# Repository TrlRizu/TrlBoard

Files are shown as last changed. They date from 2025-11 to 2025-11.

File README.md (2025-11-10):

<h1 align="center">TRL BOARD</h1>
<h3 align="center">ESP32-S3-WROOM-1 Devboard • IMU + Battery Support</h3>

--- 

## Features
 - ESP-32-S3-WROOM-1
 - ICM-42670-P IMU sensor
 - BQ24072RGT Battery Charger 
 - B2B-XH-A_LF__SN_ Connector
 - TPS63060 Buck Boost Converter
 - CH340C USB-UART bridge
 - USB-C connection
 - 1x20 x2 Connector pins (GPIO/GND/5V/3V3)

---

## PCB Schematic & Layout
#### See full [TrlBoard-schematic](schematic.pdf).

The schematic: 

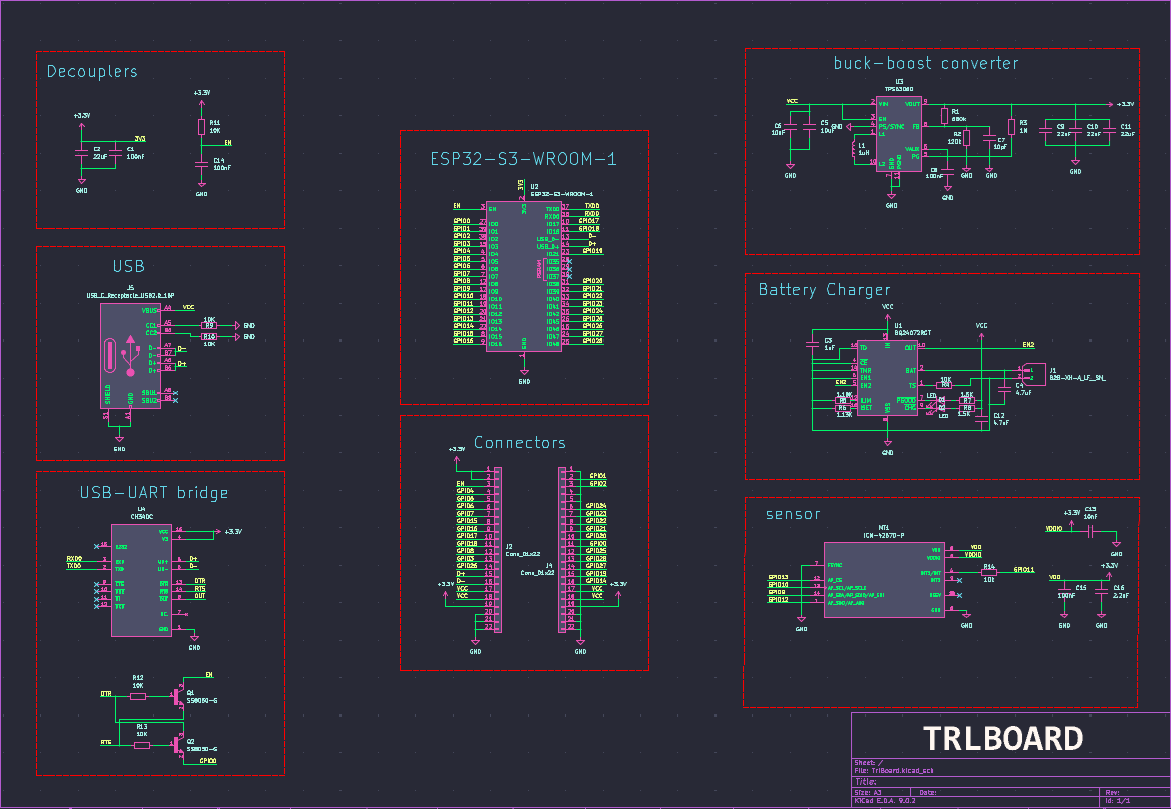
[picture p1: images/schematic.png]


Front: 
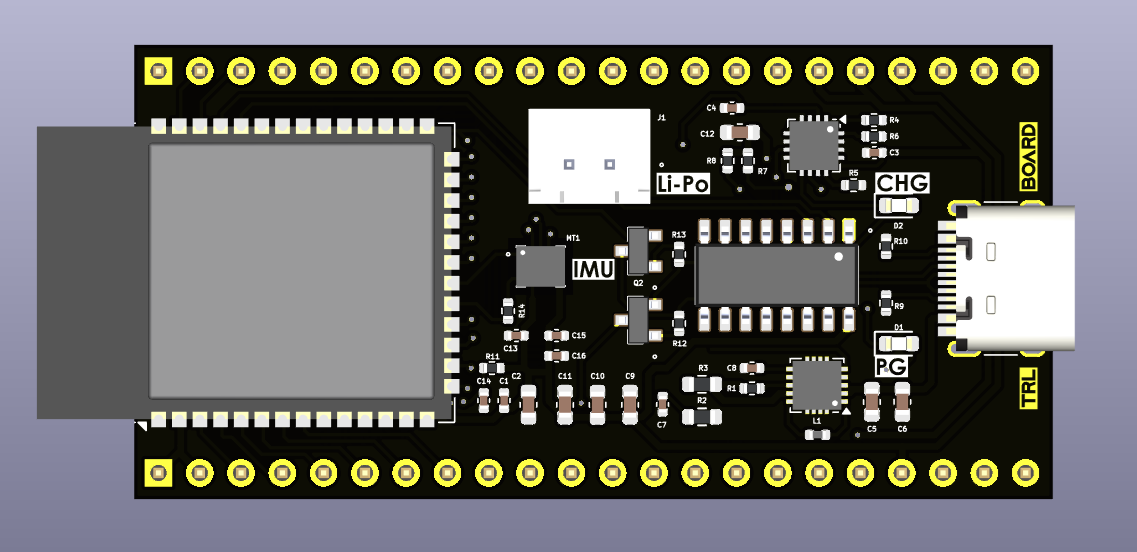
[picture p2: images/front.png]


Back: 
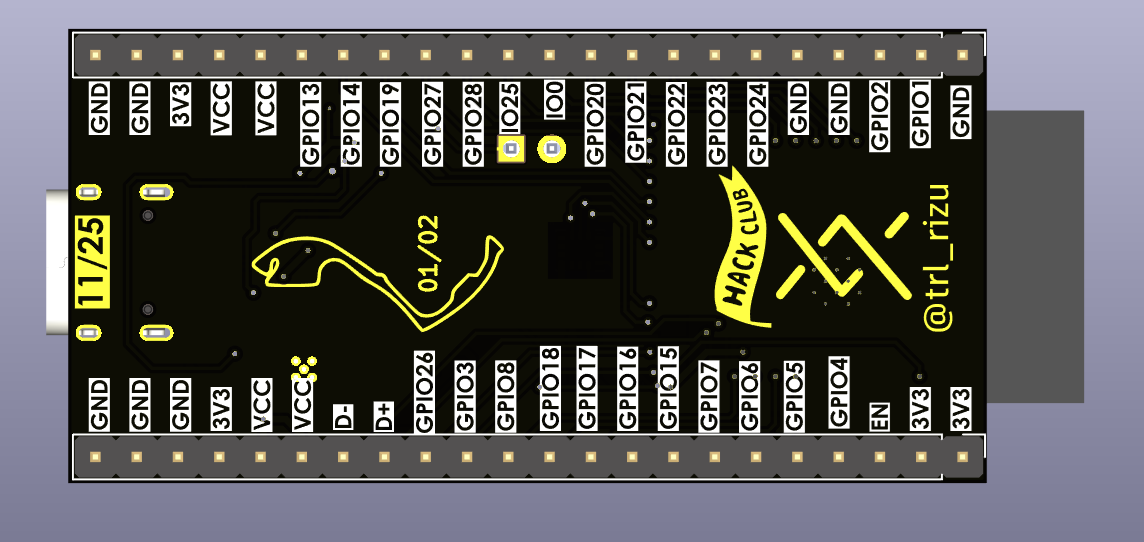
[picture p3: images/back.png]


---

## Renders

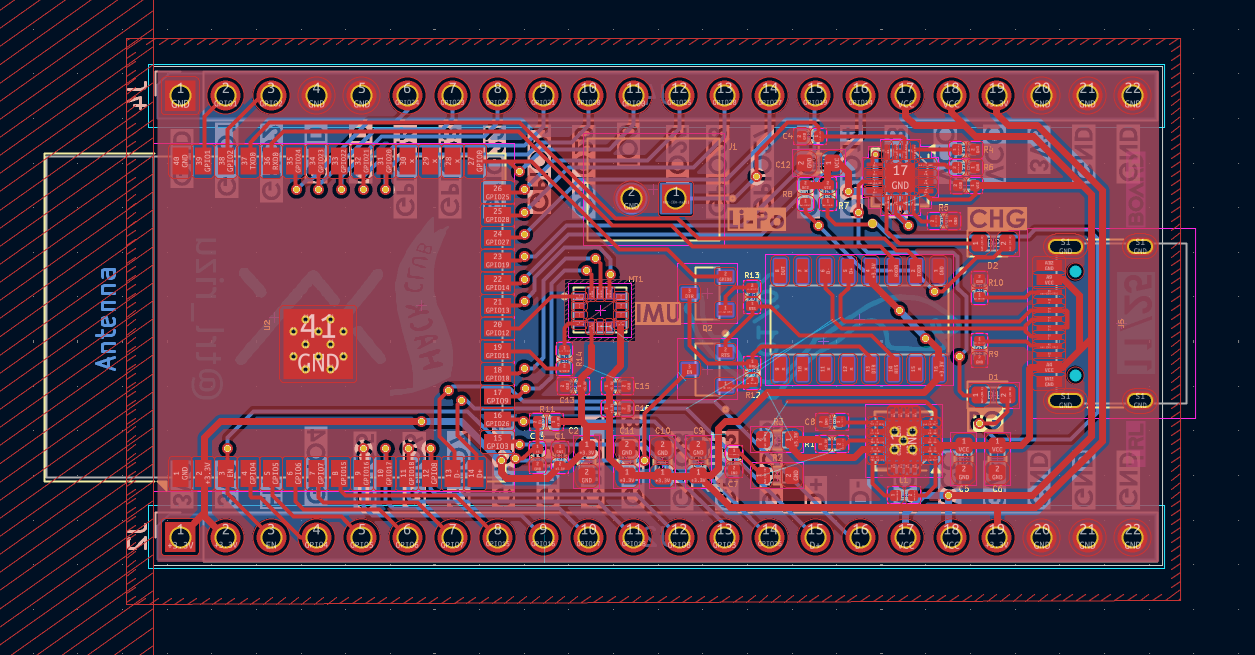
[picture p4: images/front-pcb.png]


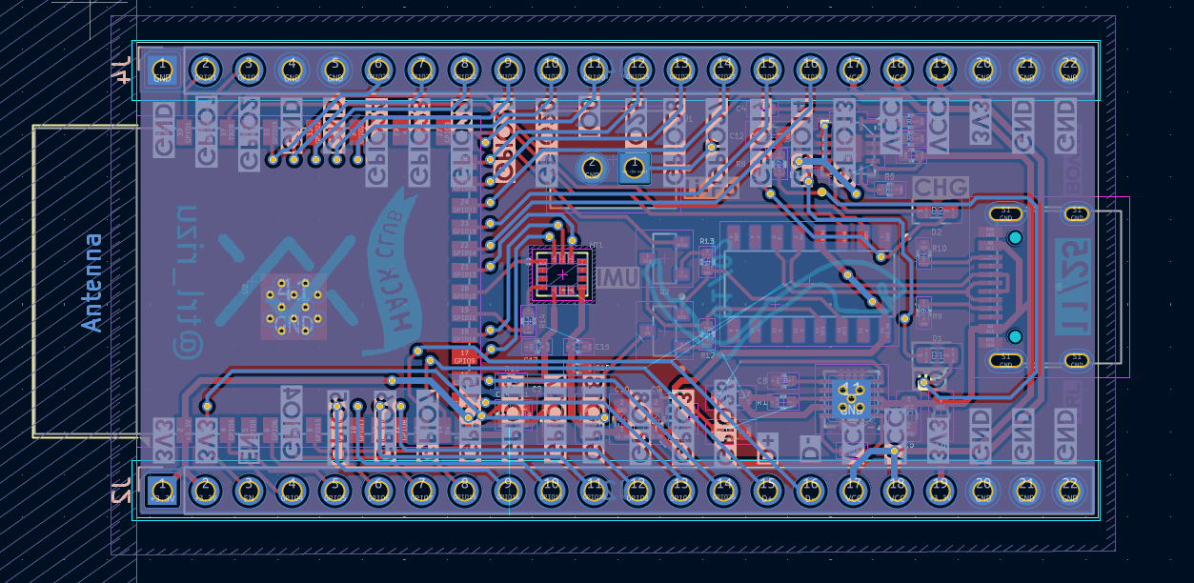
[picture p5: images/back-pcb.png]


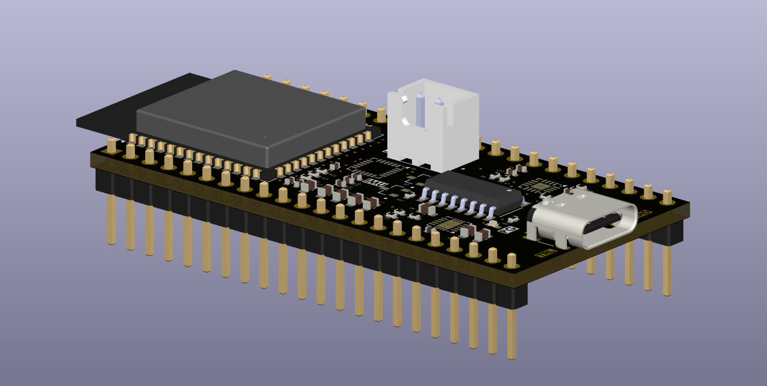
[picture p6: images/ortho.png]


---

## Bill Of Materials

The board is manufactured through JLCPCB's PCBA though not complete as the ESP32-S3-WROOM-1 and header pins are going to be hand-soldered.

> For the breakdown of the board's individual components, check check [Components](TrlBoard-Components.csv).

> For the breakdown of the PCBA components, check [Components](bom-JLCPCB-Assembly-Order.csv).

> For the breakdown of the entire cost check (PCBA + ESP32 + Connector pins + resistor) check [BOM](bom.csv) or look below.

# 🧾 Bill of Materials

| Designator | Footprint | Quantity | Qty/board | Value | Link | Cost  | Running Cost |
|---|---|---|---|---|---|---|---|
| PCBA | | 2 | | | JLCPCB | 37.99 | 37.99 |
| U2 | ESP32-S3-WROOM-1 | 2 | 1 | ESP32-S3-WROOM-1 | [AliExpress](https://www.aliexpress.com/item/1005008405001510.html?spm=a2g0o.cart.0.0.186438daN5XPTv&mp=1) | 11.58 | 49.57 |
| J2, J4 | PinHeader_1x22_P2.54mm_Vertical | 4 | 2 | Conn_01x12 | [AliExpress](https://www.aliexpress.com/item/4000988113226.html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,scm-url:1007.13440.426876.0,pvid:39fa2927-4aee-480c-89c2-457762f75e3d,tpp_buckets:668%232846%238116%232002&pdp_ext_f=%7B%22order%22%3A%221947%22%2C%22eval%22%3A%221%22%2C%22sceneId%22%3A%223440%22%2C%22fromPage%22%3A%22recommend%22%7D&utparam-url=scene%3AshoppingCartRecommend%7Cquery_from%3A%7Cx_object_id%3A4000988113226%7C_p_origin_prod%3A) | 0.9 | 50.47 |
| R1 | 402 | 2 | 1 | 680k | [AliExpress](https://www.aliexpress.com/item/1005006098766125.html?spm=a2g0o.cart.0.0.65dd38dayXF0Oh&mp=1) | 0.86  | 51.33 |
| MT1 | ICM-42670-P | 2 | 1 | ICM-42670-P | [AliExpress](https://www.aliexpress.com/item/1005009262807766.html?spm=a2g0o.cart.0.0.65dd38dayXF0Oh&mp=1) | 3.38  | 54.71 |
| | | | | | **AliExpress Tax + Shipping Fee** | 2.4 | 57.11 |
| | | | | | **Total Cost** | | **57.11** |

Note: I didn't find any 1x22 pin connectors so why not just purchase 1x30pin and then cut off the excess?

---

## Intended purpose

TRL-Board is a flexible devboard aimed to power personal robotic prototypes, with ideas such as: 
- Quadrupped Bot
- Line-follower 
- Robotic Arm Mirrored control

Ideas to follow!

---

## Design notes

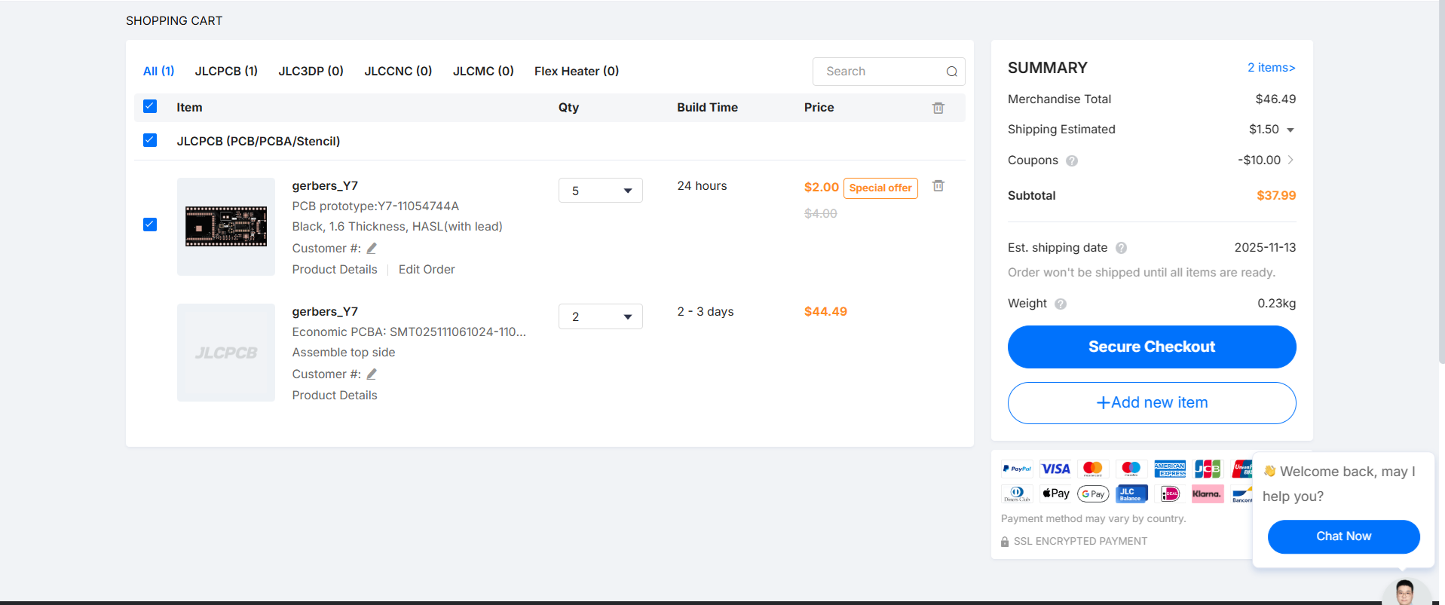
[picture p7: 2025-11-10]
images/jlcpcb.png

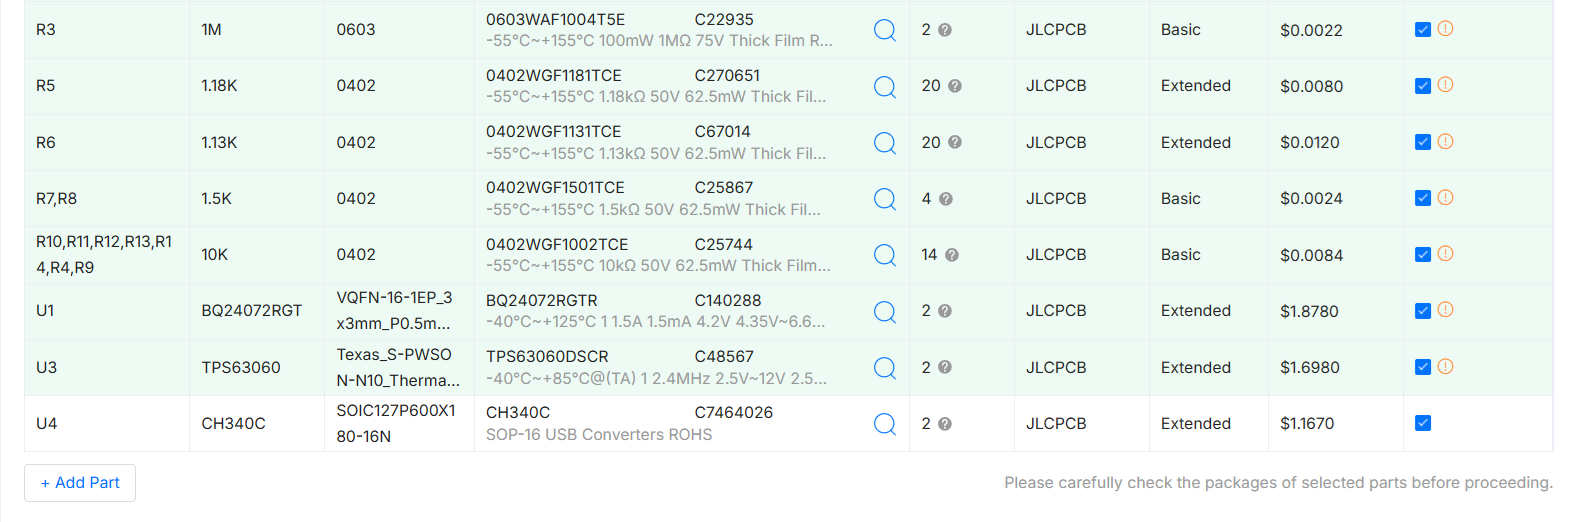
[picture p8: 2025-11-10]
images/PCBA-2.png

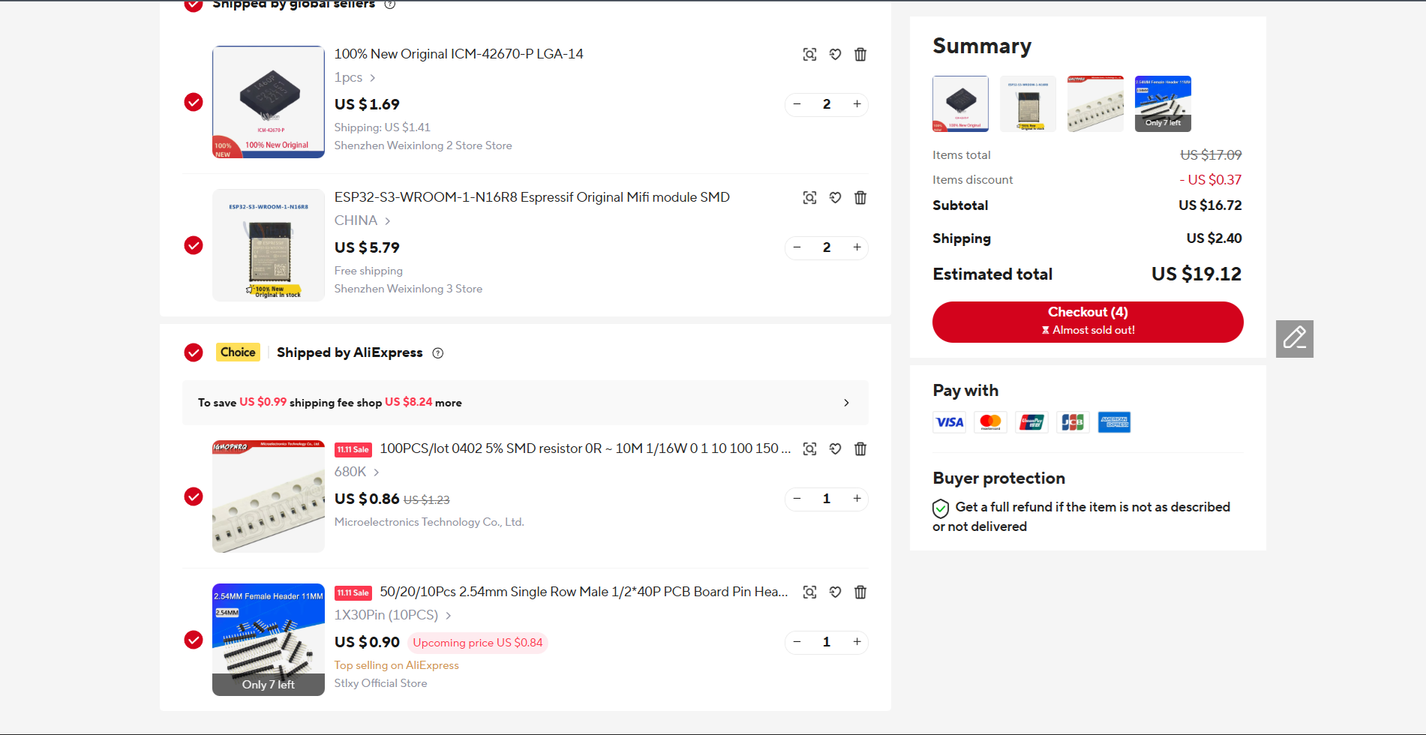
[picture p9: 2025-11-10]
images/aliExpress.png

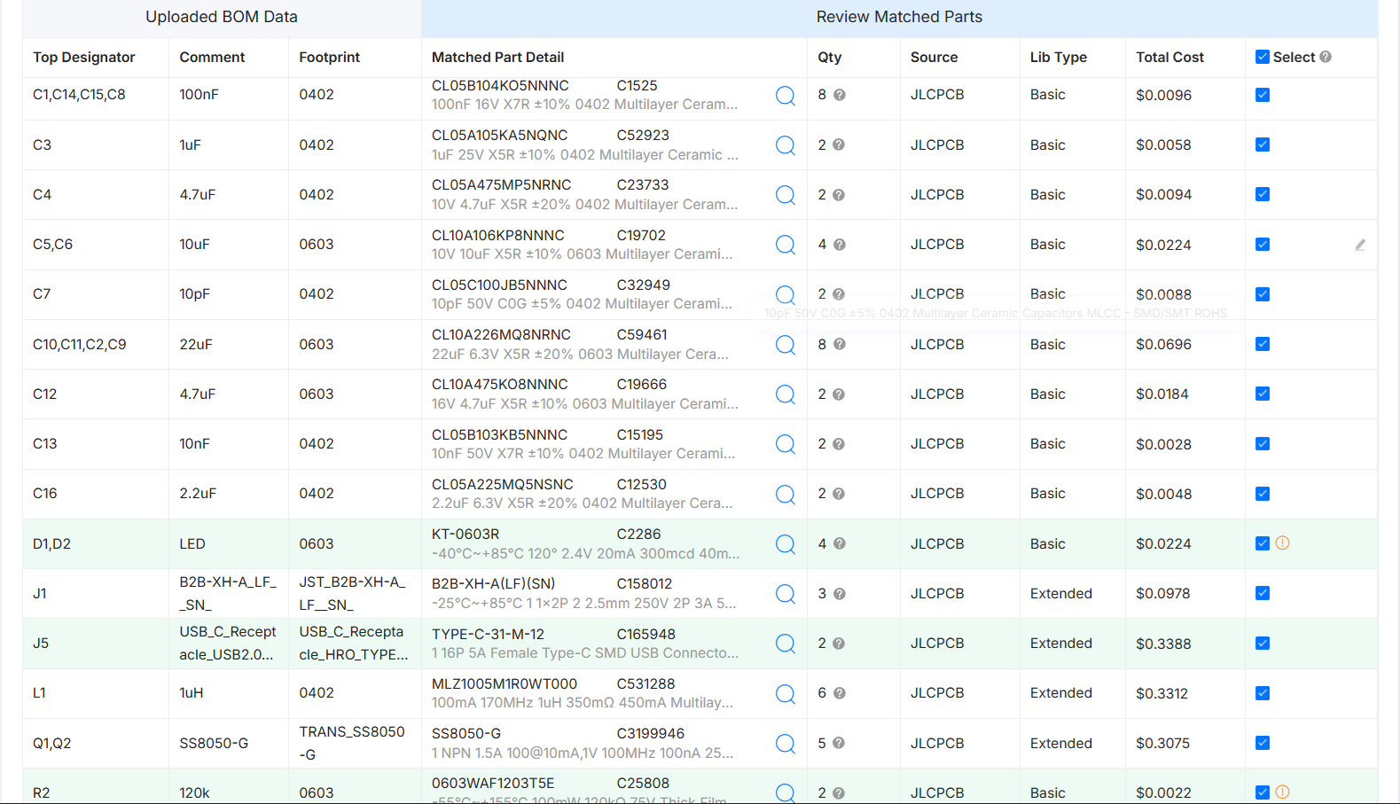
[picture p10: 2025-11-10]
images/PCBA-1.png

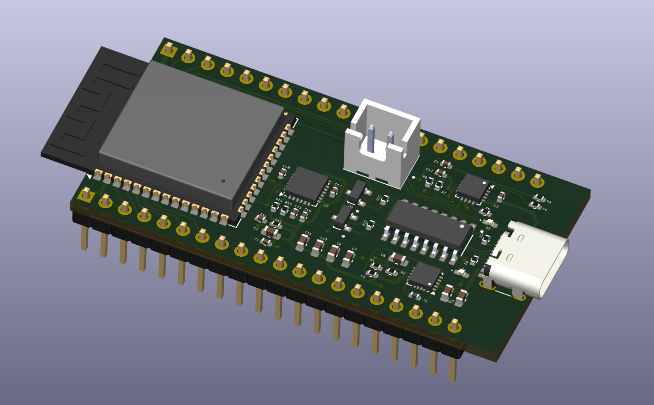
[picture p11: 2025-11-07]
images/draft.png

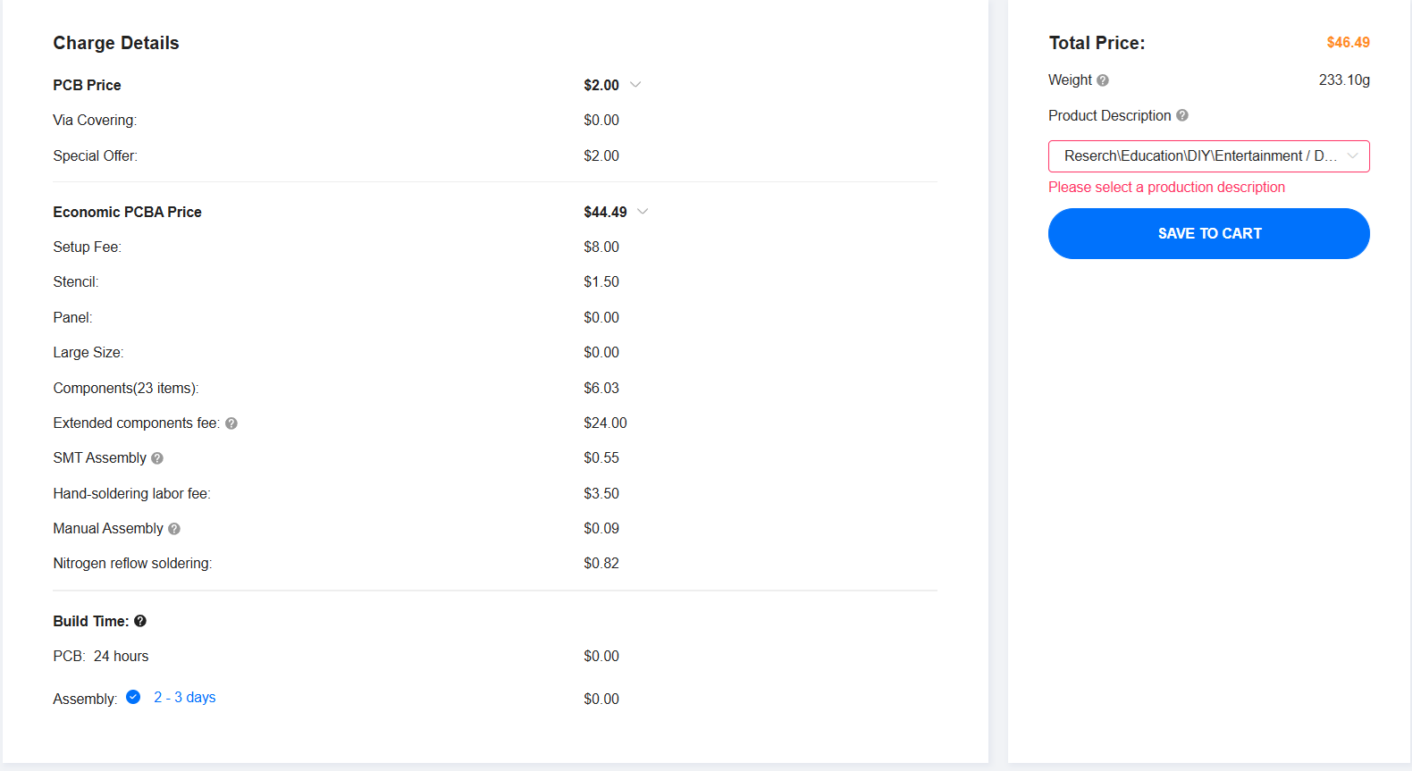
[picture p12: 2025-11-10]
images/jlcpcb-quote.png

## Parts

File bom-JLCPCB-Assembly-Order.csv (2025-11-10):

JLCPCB BOM Tool - BOM Matching
BOM name：bom-JLCPCB Assembly Order.xlsx |  |  | Download Time：2025-11-10 18:25:51 |  |  |  | * Our matching results are updated in real-time, but stock and prices may change. If it's been over 24 hours, please re-match before placing your order.
PCB Assembled Qty：5 |  |  | Est. Total Price：6.0275
Your BOM |  |  |  |  | Matched Parts |  |  |  |  |  |  | Order Information
Top Designator | Bottom Designator | Comment | Footprint | JLCPCB Part # | Matches | Part # | Manufacturer | Footprint | Description | Category | Warning | JLCPCB Part # | Product link | Lib Type | Qty | Source | Total Price ($) | Running cost
C1,C14,C15,C8 |  | 100nF | 402 |  | Select by System | CL05B104KO5NNNC | Samsung Electro-Mechanics | 402 | 100nF 16V X7R ±10% 0402 Multilayer Ceramic Capacitors MLCC - SMD/SMT ROHS | Multilayer Ceramic Capacitors MLCC - SMD/SMT |  | C1525 | https://jlcpcb.com/partdetail/1877-CL05B104KO5NNNC/C1525 | Basic | 8 | 8 JLCPCB | 0.0096 | 0.0096
C3 |  | 1uF | 402 |  | Select by System | CL05A105KA5NQNC | Samsung Electro-Mechanics | 402 | 1uF 25V X5R ±10% 0402 Multilayer Ceramic Capacitors MLCC - SMD/SMT ROHS | Multilayer Ceramic Capacitors MLCC - SMD/SMT |  | C52923 | https://jlcpcb.com/partdetail/53938-CL05A105KA5NQNC/C52923 | Basic | 2 | 2 JLCPCB | 0.0058 | 0.0154
C4 |  | 4.7uF | 402 |  | Select by System | CL05A475MP5NRNC | Samsung Electro-Mechanics | 402 | 10V 4.7uF X5R ±20% 0402 Multilayer Ceramic Capacitors MLCC - SMD/SMT ROHS | Multilayer Ceramic Capacitors MLCC - SMD/SMT |  | C23733 | https://jlcpcb.com/partdetail/24469-CL05A475MP5NRNC/C23733 | Basic | 2 | 2 JLCPCB | 0.0094 | 0.0248
C5,C6 |  | 10uF | 603 |  | Select by System | CL10A106KP8NNNC | Samsung Electro-Mechanics | 603 | 10V 10uF X5R ±10% 0603 Multilayer Ceramic Capacitors MLCC - SMD/SMT ROHS | Multilayer Ceramic Capacitors MLCC - SMD/SMT |  | C19702 | https://jlcpcb.com/partdetail/20411-CL10A106KP8NNNC/C19702 | Basic | 4 | 4 JLCPCB | 0.0224 | 0.0472
C7 |  | 10pF | 402 |  | Select by System | CL05C100JB5NNNC | Samsung Electro-Mechanics | 402 | 10pF 50V C0G ±5% 0402 Multilayer Ceramic Capacitors MLCC - SMD/SMT ROHS | Multilayer Ceramic Capacitors MLCC - SMD/SMT |  | C32949 | https://jlcpcb.com/partdetail/33914-CL05C100JB5NNNC/C32949 | Basic | 2 | 2 JLCPCB | 0.0088 | 0.056
C10,C11,C2,C9 |  | 22uF | 603 |  | Select by System | CL10A226MQ8NRNC | Samsung Electro-Mechanics | 603 | 22uF 6.3V X5R ±20% 0603 Multilayer Ceramic Capacitors MLCC - SMD/SMT ROHS | Multilayer Ceramic Capacitors MLCC - SMD/SMT |  | C59461 | https://jlcpcb.com/partdetail/60514-CL10A226MQ8NRNC/C59461 | Basic | 8 | 8 JLCPCB | 0.0696 | 0.1256
C12 |  | 4.7uF | 603 |  | Select by System | CL10A475KO8NNNC | Samsung Electro-Mechanics | 603 | 16V 4.7uF X5R ±10% 0603 Multilayer Ceramic Capacitors MLCC - SMD/SMT ROHS | Multilayer Ceramic Capacitors MLCC - SMD/SMT |  | C19666 | https://jlcpcb.com/partdetail/20375-CL10A475KO8NNNC/C19666 | Basic | 2 | 2 JLCPCB | 0.0184 | 0.144
C13 |  | 10nF | 402 |  | Select by System | CL05B103KB5NNNC | Samsung Electro-Mechanics | 402 | 10nF 50V X7R ±10% 0402 Multilayer Ceramic Capacitors MLCC - SMD/SMT ROHS | Multilayer Ceramic Capacitors MLCC - SMD/SMT |  | C15195 | https://jlcpcb.com/partdetail/15869-CL05B103KB5NNNC/C15195 | Basic | 2 | 2 JLCPCB | 0.0028 | 0.1468
C16 |  | 2.2uF | 402 |  | Select by System | CL05A225MQ5NSNC | Samsung Electro-Mechanics | 402 | 2.2uF 6.3V X5R ±20% 0402 Multilayer Ceramic Capacitors MLCC - SMD/SMT ROHS | Multilayer Ceramic Capacitors MLCC - SMD/SMT |  | C12530 | https://jlcpcb.com/partdetail/13164-CL05A225MQ5NSNC/C12530 | Basic | 2 | 2 JLCPCB | 0.0048 | 0.1516
D1,D2 |  | LED | 603 |  | Select by Customer | KT-0603R | Hubei KENTO Elec | 603 | -40℃~+85℃ 120° 2.4V 20mA 300mcd 40mW 615nm~630nm 645nm Red Water Clear 0603 LED Indication - Discrete ROHS | LED Indication - Discrete | 1.The comment (KT-0603R) of this part does not match the one (LED) provided in your BOM. Please confirm; | C2286 | https://jlcpcb.com/partdetail/Hubei_KENTOElec-KT0603R/C2286 | Basic | 4 | 4 JLCPCB | 0.0224 | 0.174
J1 |  | B2B-XH-A_LF__SN_ | JST_B2B-XH-A_LF__SN_ |  | Select by System | B2B-XH-A(LF)(SN) | JST | 插件,P=2.5mm | -25℃~+85℃ 1 1x2P 2 2.5mm 250V 2P 3A 5.75mm 7.4mm 7mm Brass K Pin PA66 Through Hole Tin UL94V-0 White XH Plugin,P=2.5mm Wire To Board Connector ROHS | Wire To Board Connector |  | C158012 | https://jlcpcb.com/partdetail/JST-B2B_XH_A_LF_SN/C158012 | Extended | 3 | 3 JLCPCB | 0.0978 | 0.2718
J5 |  | USB_C_Receptacle_USB2.0_16P | USB_C_Receptacle_HRO_TYPE-C-31-M-12 |  | Select by Customer | TYPE-C-31-M-12 | Korean Hroparts Elec | SMD | 1 16P 5A Female Type-C SMD USB Connectors ROHS | USB Connectors |  | C165948 | https://jlcpcb.com/partdetail/Korean_HropartsElec-TYPE_C_31_M12/C165948 | Extended | 2 | 2 JLCPCB | 0.3388 | 0.6106
L1 |  | 1uH | 402 |  | Select by System | MLZ1005M1R0WT000 | TDK | 402 | 100mA 170MHz 1uH 350mΩ 450mA Multilayer Inductor ±20% 0402 Inductors (SMD) ROHS | Inductors (SMD) |  | C531288 | https://jlcpcb.com/partdetail/TDK-MLZ1005M1R0WT000/C531288 | Extended | 6 | 6 JLCPCB | 0.3312 | 0.9418
Q1,Q2 |  | SS8050-G | TRANS_SS8050-G |  | Select by System | SS8050-G | Comchip | SOT-23 | 1 NPN 1.5A 100@10mA,1V 100MHz 100nA 25V 300mW 400mV@50mA,5mA 5V NPN SOT-23 Bipolar (BJT) ROHS | Bipolar (BJT) |  | C3199946 | https://jlcpcb.com/partdetail/Comchip-SS8050G/C3199946 | Extended | 5 | 5 JLCPCB | 0.3075 | 1.2493
R2 |  | 120k | 603 |  | Select by Customer | 0603WAF1203T5E | UNI-ROYAL(Uniroyal Elec) | 603 | -55℃~+155℃ 100mW 120kΩ 75V Thick Film Resistor ±1% ±100ppm/℃ 0603 Chip Resistor - Surface Mount ROHS | Chip Resistor - Surface Mount | 1.The comment (0603WAF1203T5E) of this part does not match the one (120k) provided in your BOM. Please confirm; | C25808 | https://jlcpcb.com/partdetail/26551-0603WAF1203T5E/C25808 | Basic | 2 | 2 JLCPCB | 0.0022 | 1.2515
R3 |  | 1M | 603 |  | Select by Customer | 0603WAF1004T5E | UNI-ROYAL(Uniroyal Elec) | 603 | -55℃~+155℃ 100mW 1MΩ 75V Thick Film Resistor ±1% ±100ppm/℃ 0603 Chip Resistor - Surface Mount ROHS | Chip Resistor - Surface Mount | 1.The comment (0603WAF1004T5E) of this part does not match the one (1M) provided in your BOM. Please confirm; | C22935 | https://jlcpcb.com/partdetail/23662-0603WAF1004T5E/C22935 | Basic | 2 | 2 JLCPCB | 0.0022 | 1.2537
R5 |  | 1.18K | 402 |  | Select by Customer | 0402WGF1181TCE | UNI-ROYAL(Uniroyal Elec) | 402 | -55℃~+155℃ 1.18kΩ 50V 62.5mW Thick Film Resistor ±1% ±100ppm/℃ 0402 Chip Resistor - Surface Mount ROHS | Chip Resistor - Surface Mount | 1.The comment (0402WGF1181TCE) of this part does not match the one (1.18K) provided in your BOM. Please confirm; | C270651 | https://jlcpcb.com/partdetail/260031-0402WGF1181TCE/C270651 | Extended | 20 | 20 JLCPCB | 0.008 | 1.2617
R6 |  | 1.13K | 402 |  | Select by Customer | 0402WGF1131TCE | UNI-ROYAL(Uniroyal Elec) | 402 | -55℃~+155℃ 1.13kΩ 50V 62.5mW Thick Film Resistor ±1% ±100ppm/℃ 0402 Chip Resistor - Surface Mount ROHS | Chip Resistor - Surface Mount | 1.The comment (0402WGF1131TCE) of this part does not match the one (1.13K) provided in your BOM. Please confirm; | C67014 | https://jlcpcb.com/partdetail/68102-0402WGF1131TCE/C67014 | Extended | 20 | 20 JLCPCB | 0.012 | 1.2737
R7,R8 |  | 1.5K | 402 |  | Select by Customer | 0402WGF1501TCE | UNI-ROYAL(Uniroyal Elec) | 402 | -55℃~+155℃ 1.5kΩ 50V 62.5mW Thick Film Resistor ±1% ±100ppm/℃ 0402 Chip Resistor - Surface Mount ROHS | Chip Resistor - Surface Mount | 1.The comment (0402WGF1501TCE) of this part does not match the one (1.5K) provided in your BOM. Please confirm; | C25867 | https://jlcpcb.com/partdetail/26610-0402WGF1501TCE/C25867 | Basic | 4 | 4 JLCPCB | 0.0024 | 1.2761
R10,R11,R12,R13,R14,R4,R9 |  | 10K | 402 |  | Select by Customer | 0402WGF1002TCE | UNI-ROYAL(Uniroyal Elec) | 402 | -55℃~+155℃ 10kΩ 50V 62.5mW Thick Film Resistor ±1% ±100ppm/℃ 0402 Chip Resistor - Surface Mount ROHS | Chip Resistor - Surface Mount | 1.The comment (0402WGF1002TCE) of this part does not match the one (10K) provided in your BOM. Please confirm; | C25744 | https://jlcpcb.com/partdetail/26487-0402WGF1002TCE/C25744 | Basic | 14 | 14 JLCPCB | 0.0084 | 1.2845
U1 |  | BQ24072RGT | VQFN-16-1EP_3x3mm_P0.5mm_EP1.6x1.6mm |  | Select by Customer | BQ24072RGTR | Texas Instruments | QFN-16-EP(3x3) | -40℃~+125℃ 1 1.5A 1.5mA 4.2V 4.35V~6.6V Charging IC Lithium Battery Support QFN-16-EP(3x3) Battery Management ROHS | Battery Management | 1.The comment (BQ24072RGTR) of this part does not match the one (BQ24072RGT) provided in your BOM. Please confirm; | C140288 | https://jlcpcb.com/partdetail/TexasInstruments-BQ24072RGTR/C140288 | Extended | 2 | 2 JLCPCB | 1.878 | 3.1625
U3 |  | TPS63060 | Texas_S-PWSON-N10_ThermalVias |  | Select by Customer | TPS63060DSCR | Texas Instruments | WSON-10-EP(3x3) | -40℃~+85℃@(TA) 1 2.4MHz 2.5V~12V 2.5V~8V 2A 30uA Adjustable Buck-Boost Buck-Boost Built-In Yes WSON-10-EP(3x3) DC-DC Converters ROHS | DC-DC Converters | 1.The comment (TPS63060DSCR) of this part does not match the one (TPS63060) provided in your BOM. Please confirm; | C48567 | https://jlcpcb.com/partdetail/TexasInstruments-TPS63060DSCR/C48567 | Extended | 2 | 2 JLCPCB | 1.698 | 4.8605
U4 |  | CH340C | SOIC127P600X180-16N |  | Select by System | CH340C | WCH(Jiangsu Qin Heng) | SOP-16 | SOP-16 USB Converters ROHS | USB Converters |  | C7464026 | https://jlcpcb.com/partdetail/WCH_Jiangsu_Qin_Heng-CH340C/C7464026 | Extended | 2 | 2 JLCPCB | 1.167 | 6.0275
 |  |  |  |  |  |  |  |  |  |  |  |  |  |  |  |  |  | 6.0275

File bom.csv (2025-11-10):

Designator | Footprint | Quantity | Quantity/board | Value | Link | Cost | Running Cost
PCBA |  | 2 |  |  | JLCPCB | 37.99 | 37.99
U2 | ESP32-S3-WROOM-1 | 2 | 1 | ESP32-S3-WROOM-1 | https://www.aliexpress.com/item/1005008405001510.html?spm=a2g0o.cart.0.0.186438daN5XPTv&mp=1 | 11.58 | 49.57
J2, J4 | PinHeader_1x22_P2.54mm_Vertical | 4 | 2 | Conn_01x12 | https://www.aliexpress.com/item/4000988113226.html?scm_id=1007.13440.426876.0&scm-url=1007.13440.426876.0 | 0.9 | 50.47
R1 | 402 | 2 | 1 | 680k | https://www.aliexpress.com/item/1005006098766125.html?spm=a2g0o.cart.0.0.65dd38dayXF0Oh&mp=1 | 0.86 | 51.33
MT1 | ICM-42670-P | 2 | 1 | ICM-42670-P | https://www.aliexpress.com/item/1005009262807766.html?spm=a2g0o.cart.0.0.65dd38dayXF0Oh&mp=1 | 3.38 | 54.71
AliExpress Tax + Shipping Fee |  |  |  |  |  | 2.4 | 57.11
 |  |  |  |  |  | Total Cost | 57.11

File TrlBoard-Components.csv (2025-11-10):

Designator | Value | Footprint | LCSC | Quantity | Cost | Running Cost
C1,C14,C15,C8 | 100nF | 402 | C1525 | 8 | 0.0096 | 0.0096
C3 | 1uF | 402 | C52923 | 2 | 0.0058 | 0.0154
C4 | 4.7uF | 402 | C23733 | 2 | 0.0094 | 0.0248
C5,C6 | 10uF | 603 | C19702 | 4 | 0.0224 | 0.0472
C7 | 10pF | 402 | C32949 | 2 | 0.0088 | 0.056
C10,C11,C2,C9 | 22uF | 603 | C59461 | 8 | 0.0696 | 0.1256
C12 | 4.7uF | 603 | C19666 | 2 | 0.0184 | 0.144
C13 | 10nF | 402 | C15195 | 2 | 0.0028 | 0.1468
C16 | 2.2uF | 402 | C12530 | 2 | 0.0048 | 0.1516
D1,D2 | LED | 603 | C2286 | 4 | 0.0224 | 0.174
J1 | B2B-XH-A_LF__SN_ | JST_B2B-XH-A_LF__SN_ | C158012 | 3 | 0.0978 | 0.2718
J5 | USB_C_Receptacle_USB2.0_16P | USB_C_Receptacle_HRO_TYPE-C-31-M-12 | C165948 | 2 | 0.3388 | 0.6106
L1 | 1uH | 402 | C531288 | 6 | 0.3312 | 0.9418
Q1,Q2 | SS8050-G | TRANS_SS8050-G | C3199946 | 5 | 0.3075 | 1.2493
R1 | 680k | 402 | https://www.aliexpress.com/item/1005006098766125.html?spm=a2g0o.cart.0.0.65dd38dag9kl0s&mp=1 | 2 | 0.86 | 2.1115
R2 | 120k | 603 | C25808 | 2 | 0.0022 | 2.1137
R3 | 1M | 603 | C22935 | 2 | 0.0022 | 2.1217
R5 | 1.18K | 402 | C270651 | 2 | 0.008 | 2.1337
R6 | 1.13K | 402 | C67014 | 2 | 0.012 | 2.1361
R7,R8 | 1.5K | 402 | C25867 | 4 | 0.0024 | 2.1445
R10,R11,R12,R13,R14,R4,R9 | 10K | 402 | C25744 | 14 | 0.0084 | 2.1445
J2, J4 | PinHeader_1x22_P2.54mm_Vertical | PinHeader_1x22_P2.54mm_Vertical | https://www.aliexpress.com/item/4000988113226.html?spm=a2g0o.cart.0.0.65dd38dag9kl0s&mp=1 | 4 | 0.9 | 3.0445
MT1 | ICM-42670-P | ICM-42670-P | https://www.aliexpress.com/item/1005009475826927.html?mp=1 | 2 | 3.38 | 6.4245
U1 | BQ24072RGT | VQFN-16-1EP_3x3mm_P0.5mm_EP1.6x1.6mm | C140288 | 2 | 1.878 | 8.3025
U2 | ESP32-S3-WROOM-1 | ESP32-S3-WROOM-1 | https://www.aliexpress.com/item/1005008405001510.html?spm=a2g0o.cart.0.0.186438daN5XPTv&mp=1 | 2 | 11.58 | 19.8825
U3 | TPS63060 | Texas_S-PWSON-N10_ThermalVias | C48567 | 2 | 1.698 | 21.5805
U4 | CH340C | SOIC127P600X180-16N | C7464026 | 2 | 1.167 | 22.7475

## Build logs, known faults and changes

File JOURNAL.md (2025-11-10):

<!--
  ===================    !!READ THIS NOTICE!!   ====================
  DO NOT edit this file manually. Your changes WILL BE OVERWRITTEN!
  This journal is auto generated and updated by Hack Club Blueprint.
  To edit this file, please edit your journal entries on Blueprint.
  ==================================================================
-->

## 10/25/2025 - Research + schematics draft  

Greetings, I am planning to make a custom devboard based on the ESP32-S3-Wroom1 with the size of a raspberry pi pico. I do intend however to have an IMU for future robotics/IOT projects, I think that would be a great addition to this board since the only devboard I am aware of that has that is the arduino nano IOT. 

Since the WROOM1 has WIFI, BLE, Antenna etc built in that would really save a lot of costs and parts that has to fit into the sufficient yet constrained space that we have. I do also know for a fact after researching that ESP32 has its own devkit in that size, so I guess what sets my project apart is the IMU. 

Below is the early draft of parts, after researching (tho not complete yet), I would need. All things still not yet final apart from the esp32 of course. We've got:

- ESP32-S3-WROOM1
- TPS63060 (buck-boost converter)
- BQ24072RGT (Li-Po battery charger)
- B2B-XH-A_LF__SN_ (Li-Po connector)
- USB-C receptacle
- Connector 01x20
- (CP2102N-Axx-xQFN20) USB-UART
- ASM330LHHXTR (IMU)



## 10/27/2025 - Drafting Schematic pt2  

I found out that the ASM330LHHXTR was way too expensive of an IMU for a hobbyist. And so I looked for alternatives, lo and behold, the MPU-6050:


I struggled with the idea of, how would I classify this, boot-loading? What I mean to say is the question of how I was going to program my board. I found that the ESP32-devkit-C had two buttons: boot and reset. 
What were they?
BOOT: pulls LOW to enter bootloader
RESET: pull LOW to reset chip
ok cool, but I know that I can just program an Arduino board by connecting it to the PC via USB? 
Yes, and that's possible because of a pre-installed bootloader and USB-UART bridge that handles the reset.
So now I needed a USB-UART bridge (I already had one but I didn't know what it was for); I ended up switching to CH340C copying Arduino Nano's -cheap and works perfectly.
And then I noticed some pins on the CH340C [datasheet](https://datasheet.lcsc.com/lcsc/Jiangsu-Qin-Heng-CH340C_C84681.pdf) that puzzled me: DTS & RTS
After reading, I found that they are control signals that would allow me to ditch the buttons. My IDE can toggle them to automatically reset the ESP32 and the bootloader. Also thanks to the ROM-bootloader I wouldn't have to install anything extra.



## 10/30/2025 - Routing PCB draft  

The plan of making it in somewhat the size of a Raspberry Pi Pico is still on full steam. This is the first draft. Not every passive is there, but I think I've spent long enough for today drafting this:



Also, you may have noticed that the DHT11 sensor is not on the board. That is intentional as I am in a dilemma: to include or not to. It arose from its placement requirements, it can't be near ICs as they may tamper with the accuracy of the sensor. Plus the IMU as well have to be placed more meticulously and I still hadn't figured out where I would be positioning it. Below is the attached photo of the DHT which I had tried including a while ago:



## 11/1/2025 - Routing again  

I've got to plan my layout once again. I opted to place the battery charger and the buck-boost converter on opposite sides almost mirrored on the USB and USB-UART bridge line:

But I do really need to make this neater, it doesn't look so appealing to me...



Future additions:
- NTC thermistor
- SMD temp sensors

there was a suggestion to me to tackle the sensitivity:
"place a connector and have a long NTC probe"  

## 11/4/2025 - Finished routing  

A rough look on how the board will look like. I don't quite like the large space at the bottom after the connector pins. Feels too bold. Looks too weird.

I guess I'm struggling with the layout, I don't know if that battery connector is gonna disrupt the IMU's accuracy. Need to verify with the community if that layout is alright. Will also ask the community for tips on improving the layout!





## 11/5/2025 - Re-routed PCB  

Rather quick re-routing. I just pushed my components upward so now it's more compact.
This morning as I was scrolling through youtube I saw [Phil's vid](https://www.youtube.com/watch?v=M6_an34wQJk). That helped a lot with routing, but unfortunately I am still running into some problems with the DRC. Dominated by the error: thermal relief connection to zone incomplete, I can't quite find a solution to that yet.





I shall fix that error in the next journal

Edit: lol it was a quick fix, it didn't need another journal at all
So for the copper fills, it was just as easy as selecting solid instead of thermal reliefs. I also forgot to put a keep-out rule for the IMU which I did now :D

 

## 11/6/2025 - Increased pins + aesthetics  

I increased the pins to 22 on each side after receiving advice from fellow hackClubbers. Not much trouble with routing there. I think I've gotten the hang of it.



Today, I finalized the PCB color to be black and added my personal touch to the board:


What took a long time was figuring out a way to make things more interesting with the board. I dug up Kai's message about the placement of which layer a vector image should be in. I found this


I wanted that shiny silver/gold for my elements. This was simply done by using the image converter from kicad. I created a footprint library for it and uploaded them on the layer F.Mask (B.Mask more accurately). I can't wait to manufacture this board!

## 11/7/2025 - BOM  

Upon finding out that JLCPCB does not support ESP32-S3-WROOM1 for Economic PCBA, I headed to #blueprint to ask about alternatives. They replied:
1). Tbh if possible just hand solder it. Esp modules are not that hard to hand solder
2). the wroom 32e 8mb has economy pcba
3). ESP32-WROVER-B-N8R8
4). ESP32-WROVER-E-N8R8

Frankly I evaluated options with the intent to not have an extravagant schematic + pcb layout overhaul. I was fine with a few re-routes if the pins are not far too distinct. I then immersed myself into its respective datasheets and to my surprise I convinced myself that I am alright with hand-soldering the ESP32-S3-WROOM-1. What did? The dual-core XTensa LX7 of this module was too difficult to pass on. Perhaps the WROVER-E can get to 1/4th of its capability but I intend to use this devboard for future robotics projects and having a core that's ready for ML is a huge++. 







## 11/10/2025 - IMU change + Cost optimization  

I asked the community if there are any alternatives to MPU6050 as it just is too costly. ICM-42670-P was suggested to me since it is newer and cheaper! I rerouted the board, no major changes, took out a few passives only.



At that point the board was still costly due to the extended parts (about $30 worth). So I tried my figuring out resistors with basic libs either by making them 0603 footprint or rounding it up to the nearest basic resistor value. I did the calculations ofc to make it safe and reduced it further to $24 worth of extended parts. Now the PCBA costs $47

I am sourcing the ESP32, the ICM-42670-P and the 680k resistor (it was extended figured that it would save costs). 



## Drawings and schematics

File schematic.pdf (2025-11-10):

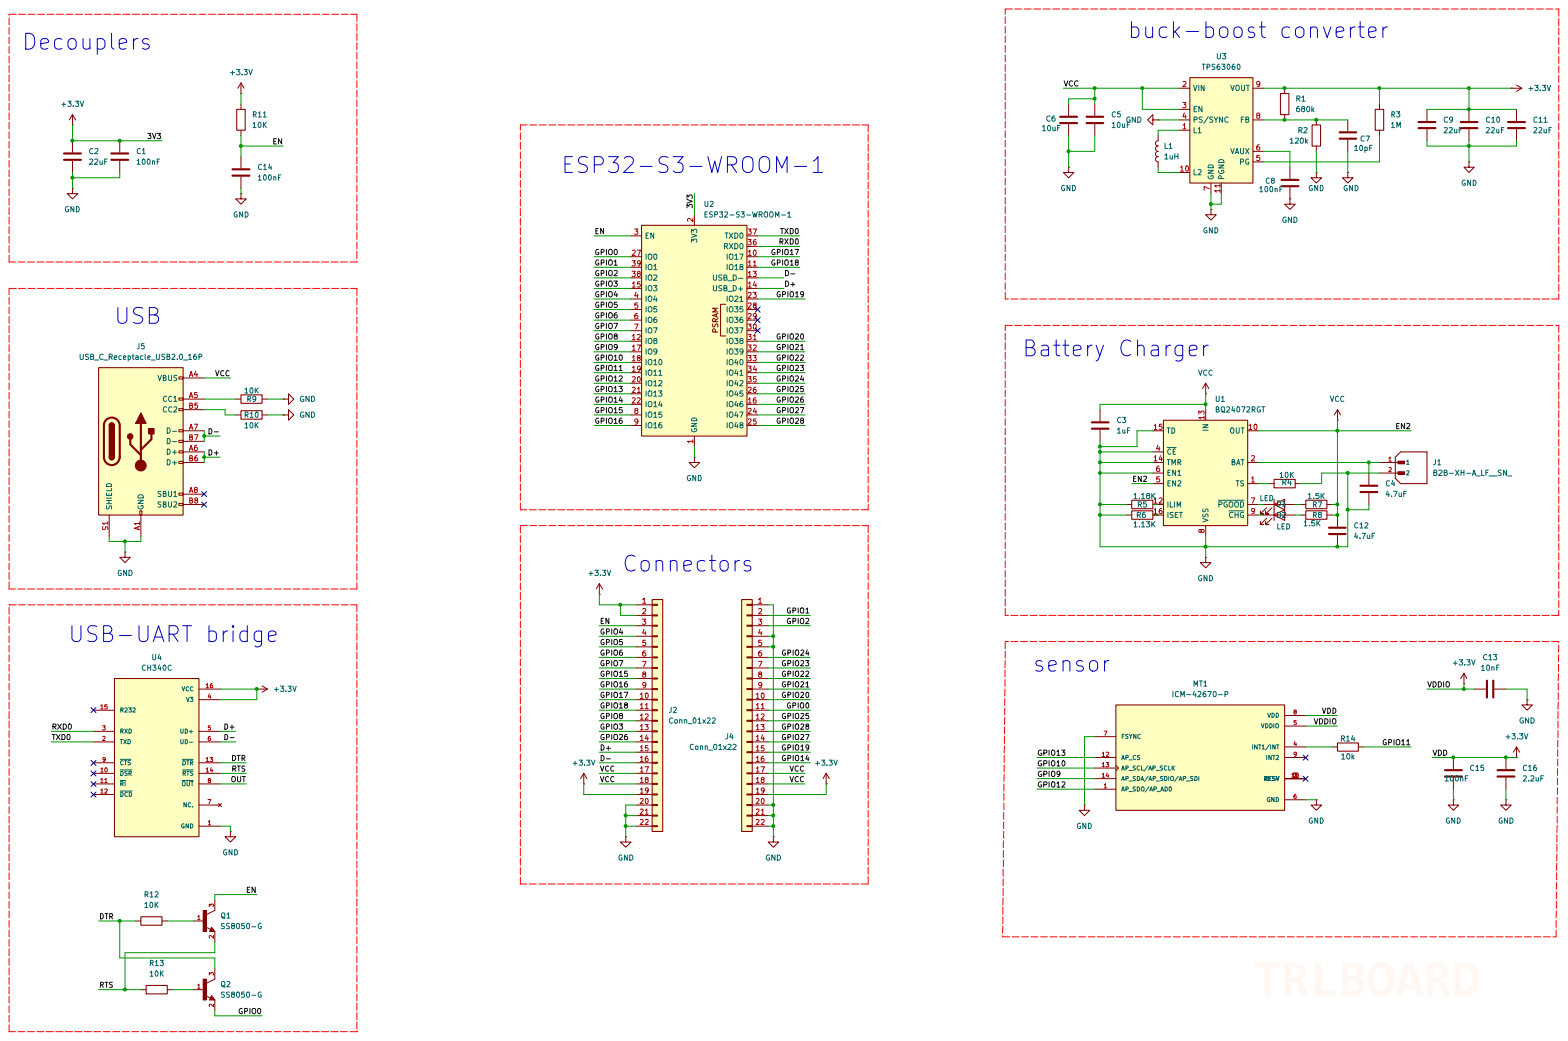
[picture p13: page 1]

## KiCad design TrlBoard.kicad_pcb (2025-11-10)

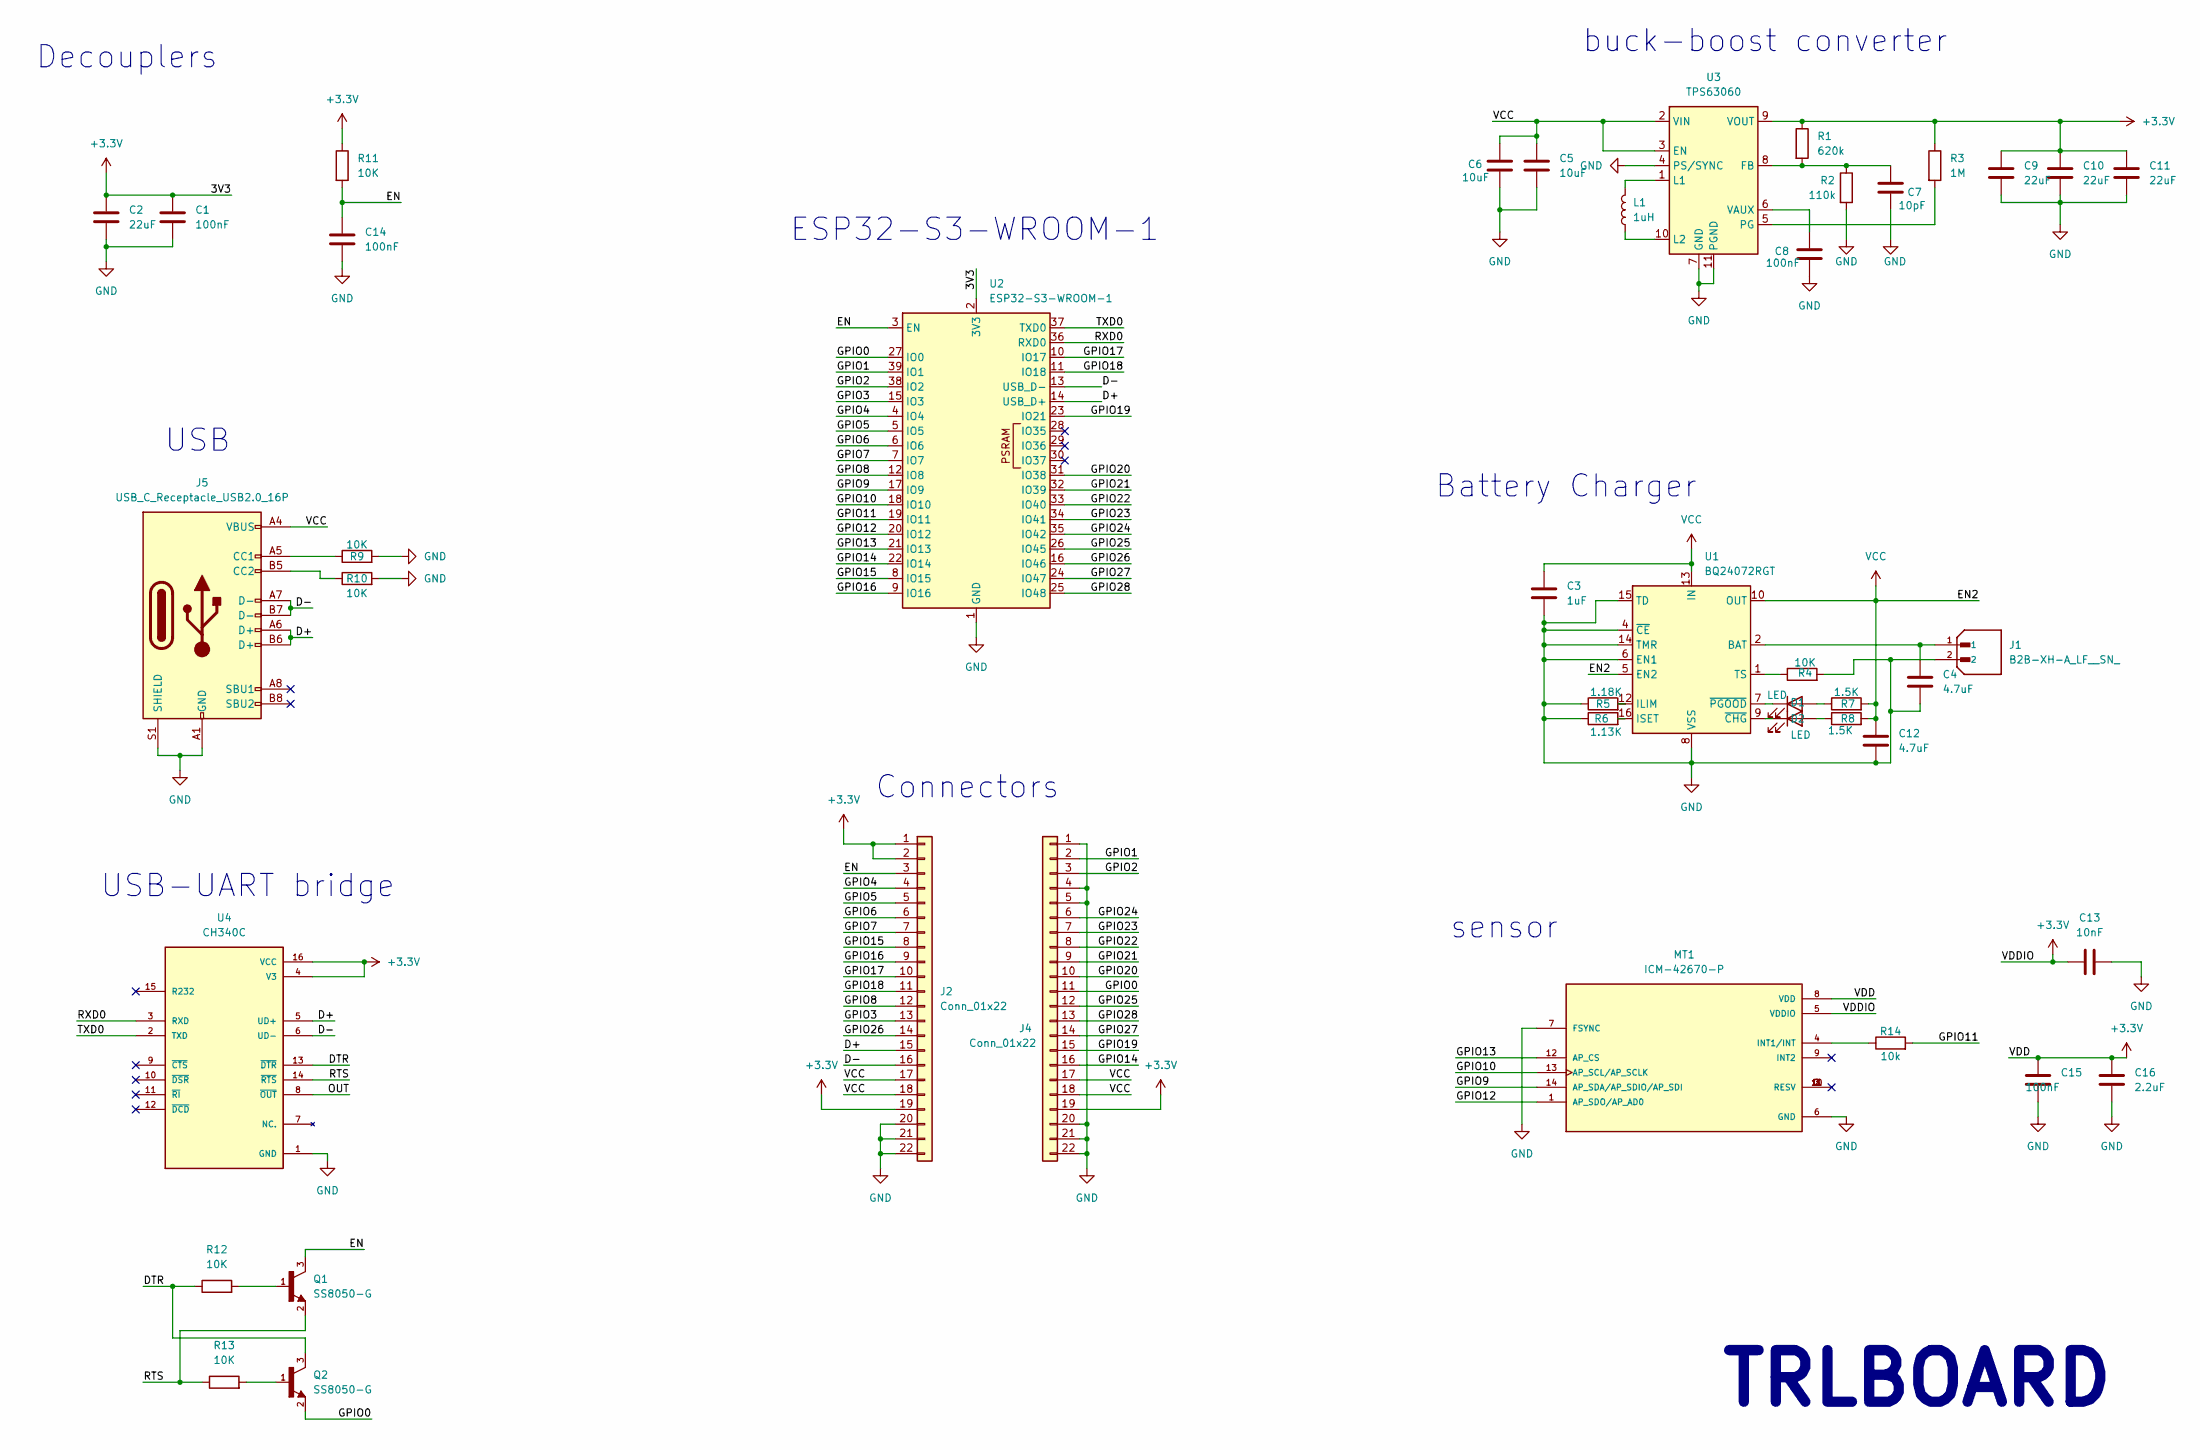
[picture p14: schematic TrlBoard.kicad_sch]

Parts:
C1, C8, C14, C15: 100nF; C_0402_1005Metric
C2, C9, C10, C11: 22uF; C_0603_1608Metric
C3: 1uF; C_0402_1005Metric
C4: 4.7uF; C_0402_1005Metric
C5, C6: 10uF; C_0603_1608Metric
C7: 10pF; C_0402_1005Metric
C12: 4.7uF; C_0603_1608Metric
C13: 10nF; C_0402_1005Metric
C16: 2.2uF; C_0402_1005Metric
D1, D2: LED; LED_0402_1005Metric_Pad0.77x0.64mm_HandSolder
J1: B2B-XH-A_LF__SN_; JST_B2B-XH-A_LF__SN_; PARTREV N/A
J2, J4: Conn_01x22; PinHeader_1x22_P2.54mm_Vertical
J5: USB_C_Receptacle_USB2.0_16P; USB_C_Receptacle_HRO_TYPE-C-31-M-12
L1: 1uH; L_0402_1005Metric
MT1: ICM-42670-P; XDCR_ICM-42670-P; PARTREV 1.1
Q1, Q2: SS8050-G; TRANS_SS8050-G; PARTREV A
R1: 620k; R_0402_1005Metric
R2: 110k; R_0402_1005Metric
R3: 1M; R_0603_1608Metric
R4, R9, R10, R11, R12, R13: 10K; R_0402_1005Metric
R5: 1.18K; R_0402_1005Metric
R6: 1.13K; R_0402_1005Metric
R7, R8: 1.5K; R_0402_1005Metric
R14: 10k; R_0402_1005Metric
U1: BQ24072RGT; VQFN-16-1EP_3x3mm_P0.5mm_EP1.6x1.6mm
U2: ESP32-S3-WROOM-1
U3: TPS63060; Texas_S-PWSON-N10_ThermalVias
U4: CH340C; SOIC127P600X180-16N; PARTREV 2G

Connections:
+3.3V: C1.2, C2.1, C9.1, C10.1, C11.1, C13.1, C15.1, C16.1, J2.1, J2.2, J2.19, J4.19, MT1.5 (VDDIO), MT1.8 (VDD), R1.1, R3.1, R11.1, U2.2 (3V3), U3.9 (VOUT), U4.4 (V3), U4.16 (VCC)
/D+: J2.15, J5.A6 (D+), J5.B6 (D+), U2.14 (USB_D+), U4.5 (UD+)
/D-: J2.16, J5.A7 (D-), J5.B7 (D-), U2.13 (USB_D-), U4.6 (UD-)
/DTR: Q2.3, R12.1, U4.13 (~DTR)
/EN: C14.1, J2.3, Q1.3, R11.2, U2.3 (EN)
/GPIO0: J4.11, Q2.2, U2.27 (IO0)
/GPIO1: J4.2, U2.39 (IO1)
/GPIO2: J4.3, U2.38 (IO2)
/GPIO3: J2.13, U2.15 (IO3)
/GPIO4: J2.4, U2.4 (IO4)
/GPIO5: J2.5, U2.5 (IO5)
/GPIO6: J2.6, U2.6 (IO6)
/GPIO7: J2.7, U2.7 (IO7)
/GPIO8: J2.12, U2.12 (IO8)
/GPIO9: MT1.14 (AP_SDA/AP_SDIO/AP_SDI), U2.17 (IO9)
/GPIO10: MT1.13 (AP_SCL/AP_SCLK), U2.18 (IO10)
/GPIO11: R14.2, U2.19 (IO11)
/GPIO12: MT1.1 (AP_SDO/AP_AD0), U2.20 (IO12)
/GPIO13: MT1.12 (AP_CS), U2.21 (IO13)
/GPIO14: J4.16, U2.22 (IO14)
/GPIO15: J2.8, U2.8 (IO15)
/GPIO16: J2.9, U2.9 (IO16)
/GPIO17: J2.10, U2.10 (IO17)
/GPIO18: J2.11, U2.11 (IO18)
/GPIO19: J4.15, U2.23 (IO21)
/GPIO20: J4.10, U2.31 (IO38)
/GPIO21: J4.9, U2.32 (IO39)
/GPIO22: J4.8, U2.33 (IO40)
/GPIO23: J4.7, U2.34 (IO41)
/GPIO24: J4.6, U2.35 (IO42)
/GPIO25: J4.12, U2.26 (IO45)
/GPIO26: J2.14, U2.16 (IO46)
/GPIO27: J4.14, U2.24 (IO47)
/GPIO28: J4.13, U2.25 (IO48)
/OUT: U4.8 (~OUT)
/RTS: Q1.2, R13.1, U4.14 (~RTS)
/RXD0: U2.36 (RXD0), U4.3 (RXD)
/TXD0: U2.37 (TXD0), U4.2 (TXD)
GND: C1.1, C2.2, C3.2, C4.2, C5.2, C6.2, C7.2, C8.2, C9.2, C10.2, C11.2, C12.2, C13.2, C14.2, C15.2, C16.2, J1.2, J2.20, J2.21, J2.22, J4.1, J4.4, J4.5, J4.20, J4.21, J4.22, J5.A1 (GND), J5.A12 (GND), J5.B1 (GND), J5.B12 (GND), J5.S1 (SHIELD), MT1.6 (GND), MT1.7 (FSYNC), R2.2, R4.2, R5.1, R6.1, R9.2, R10.2, U1.4 (~CE), U1.6 (EN1), U1.8 (VSS), U1.14 (TMR), U1.15 (TD), U1.17 (VSS), U2.1 (GND), U2.40 (GND), U2.41 (GND), U3.4 (PS/SYNC), U3.7 (GND), U3.11 (PGND), U4.1 (GND)
unnamed: C4.1, J1.1, U1.2 (BAT), U1.3 (BAT)
unnamed: D1.2 (A), R7.1
unnamed: D1.1 (K), U1.7 (~PGOOD)
unnamed: D2.2 (A), R8.1
unnamed: D2.1 (K), U1.9 (~CHG)
unnamed: J5.A5 (CC1), R9.1
unnamed: J5.B5 (CC2), R10.1
unnamed: MT1.4 (INT1/INT), R14.1
unnamed: Q1.1, R12.2
unnamed: Q2.1, R13.2
unnamed: R5.2, U1.12 (ILIM)
unnamed: R6.2, U1.16 (ISET)
unnamed: R4.1, U1.1 (TS)
unnamed: C7.1, R1.2, R2.1, U3.8 (FB)
unnamed: L1.2, U3.1 (L1)
unnamed: L1.1, U3.10 (L2)
unnamed: R3.2, U3.5 (PG)
unnamed: C8.1, U3.6 (VAUX)
VCC: C3.1, C5.1, C6.1, C12.1, J2.17, J2.18, J4.17, J4.18, J5.A4 (VBUS), J5.A9 (VBUS), J5.B4 (VBUS), J5.B9 (VBUS), R7.2, R8.2, U1.5 (EN2), U1.10 (OUT), U1.11 (OUT), U1.13 (IN), U3.2 (VIN), U3.3 (EN)

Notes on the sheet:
sensor
Decouplers
Battery Charger
ESP32-S3-WROOM-1
USB
USB-UART bridge
TRLBOARD
Connectors
buck-boost converter

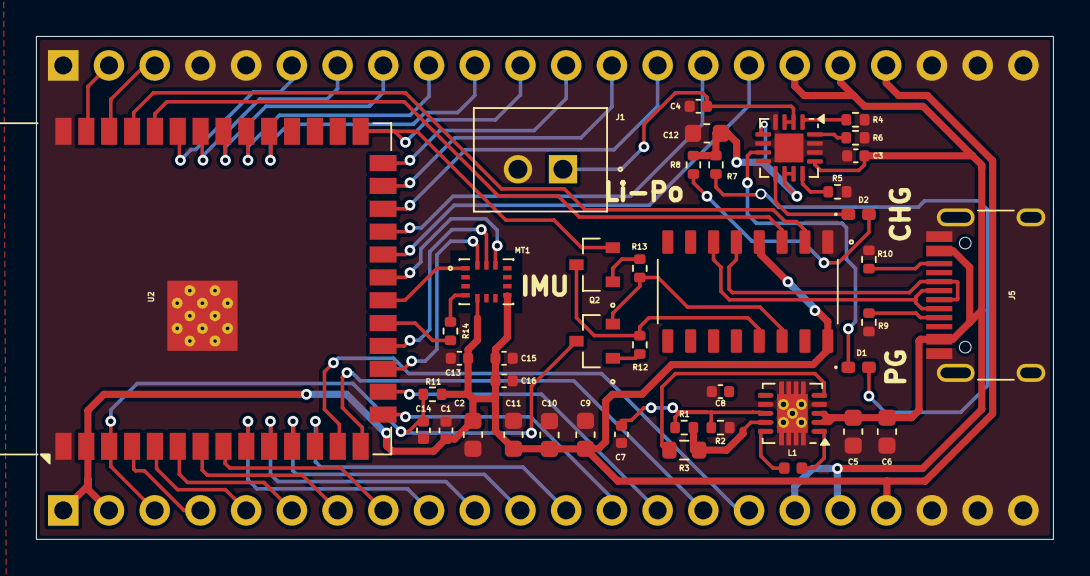
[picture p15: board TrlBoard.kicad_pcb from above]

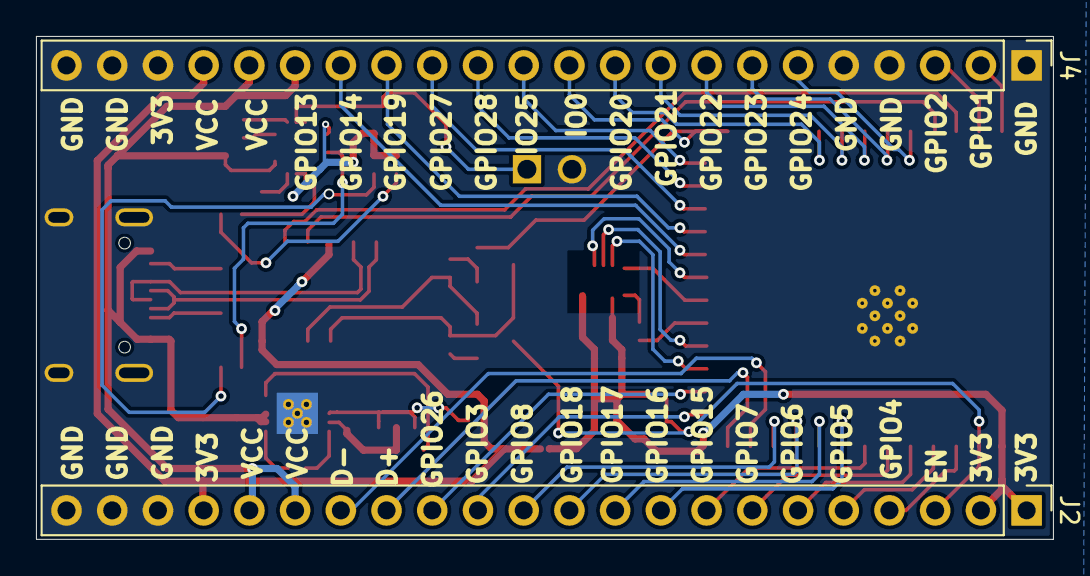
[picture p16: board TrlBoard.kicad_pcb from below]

Board: 2 copper layers, 56.5 x 27.9 mm, 44 parts (2 on the bottom side), 57 nets.

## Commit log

2025-11-07 updated bom
    [TrlBoard - Copponents.csv, TrlBoard-Bom.csv, TrlBoard-Components.csv]
2025-11-07 Updated bom + README
    [TrlBoard-Bom.csv]
2025-11-07 1x30 pin connector
    [TrlBoard - Copponents.csv, TrlBoard-Bom.csv, bom.csv]
2025-11-07 Fixed typos
    [TrlBoard-Components.csv]
2025-11-10 ICM + Update cost
    [TrlBoard-Components.csv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]
